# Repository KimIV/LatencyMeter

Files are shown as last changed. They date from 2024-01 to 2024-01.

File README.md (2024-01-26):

# Latency Meter Camera

Устройство для измерения раздержки различных камер и FPV-систем. Оно построено на плате Ардуино Нано и 4х разрядном 7ми-сегментном индиаторе LED 5461AS-1.

**Кнопка:**  Короткое (до 0,5 сек) нажатие переключает показания индикатора между real-time, min, max и sma. Нажатие длительностью от 0,5 до 1,5 сек останавливает и продолжает процесс измерения. Нажатие длительностью более 1,5 сек запускает процесс измерения сначала.

**Внимание!** Программный код поддерживает ТРИ разных взаимных расположения индкатора LED 5461AS и Arduino Nano. Выберите для себя нужную компоновку и задайте правильное значение константы LOCATION_LED5461AS в файле latencymeter.ino. Там же читайте подробности в комментариях перед определением константы LOCATION_LED5461AS.

Видео по сборке для компоновки LOCATION_LED5461AS 0: [https://www.youtube.com/watch?v=69uGeqPZ3CI](https://www.youtube.com/watch?v=69uGeqPZ3CI)



22.01.2024
Добавлены 3Д модели (папка 3D_Model_OutSensors) корпуса устройства для варианта сборки с выносными фоторезистором и светодиодом. Этот вариант удобнее для измерения задержек FPV-систем от курсовой камеры на квадрокоптере до шлема или очков.

24.01.2024
Добавлены 3Д модели держателей выносных элементов, параметры печати, готовые gcode и картинки. Публикация на тему сборки компоновки LOCATION_LED5461AS 1: http://chipgu.ru/viewtopic.php?t=5411

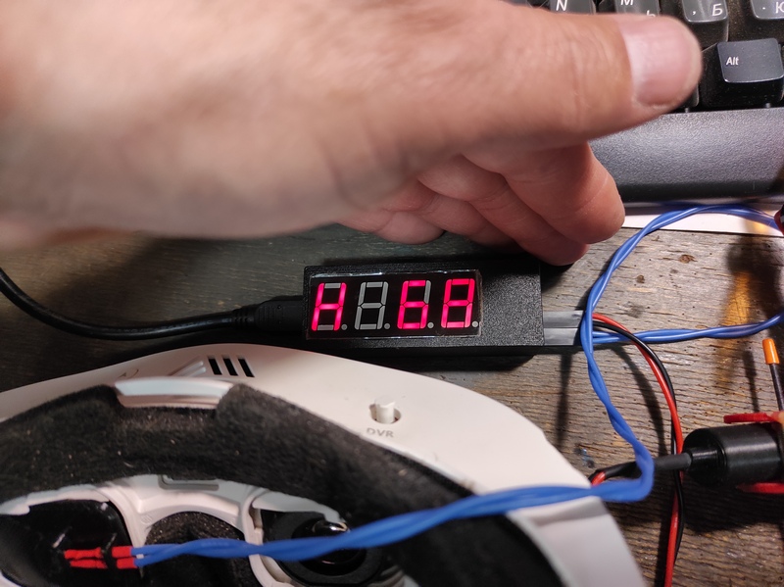
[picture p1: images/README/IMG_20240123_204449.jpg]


26.01.2024
Добавлена новая функция кнопки - возможность остановки/продолжения процесса измерения.

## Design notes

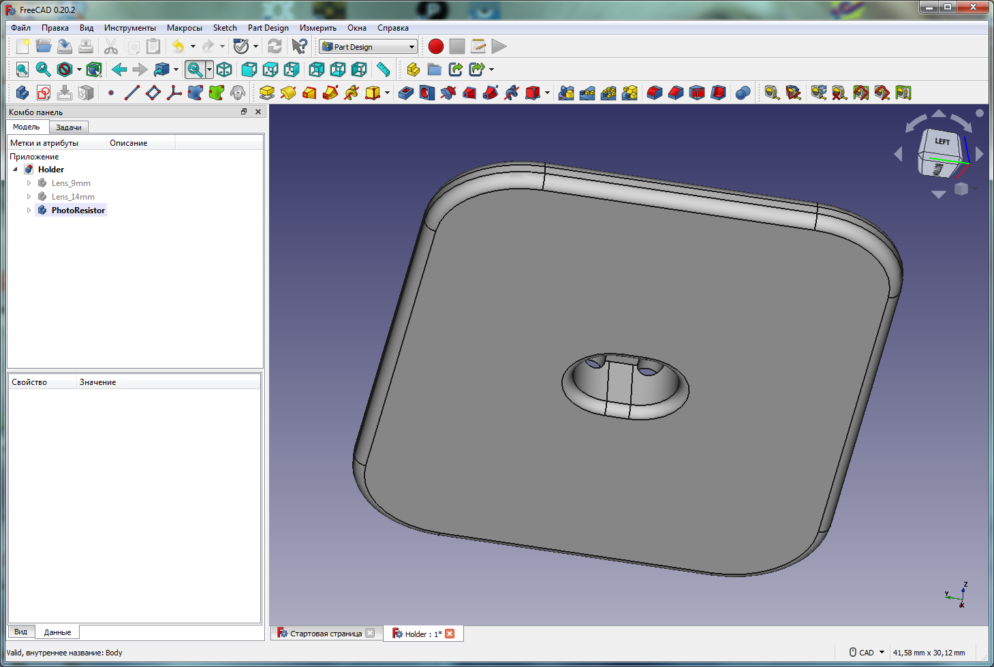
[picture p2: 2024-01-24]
3D_Model_OutSensors/Holder-PhotoResistor_3.png

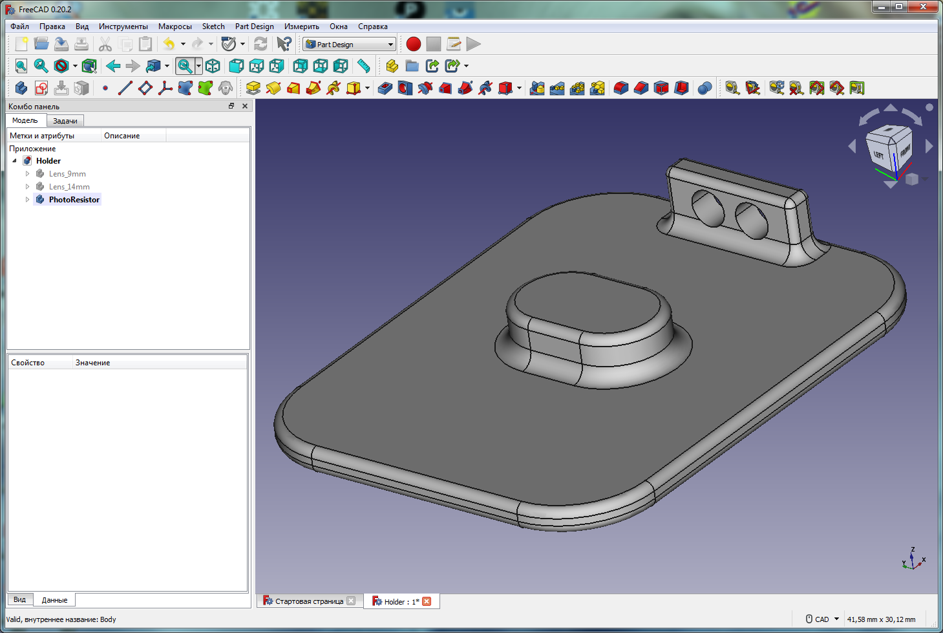
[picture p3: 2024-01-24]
3D_Model_OutSensors/Holder-PhotoResistor_1.png

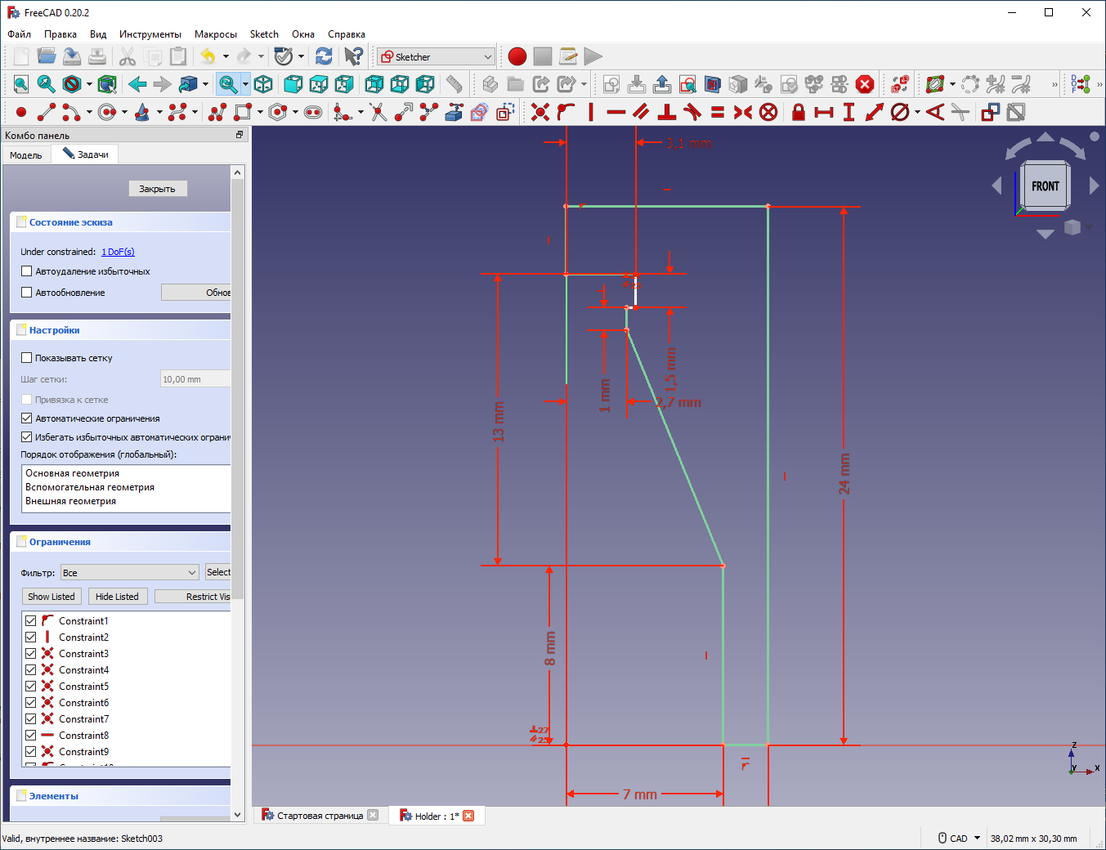
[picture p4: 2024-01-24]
3D_Model_OutSensors/Holder-Lens_14mm_Sketch.png

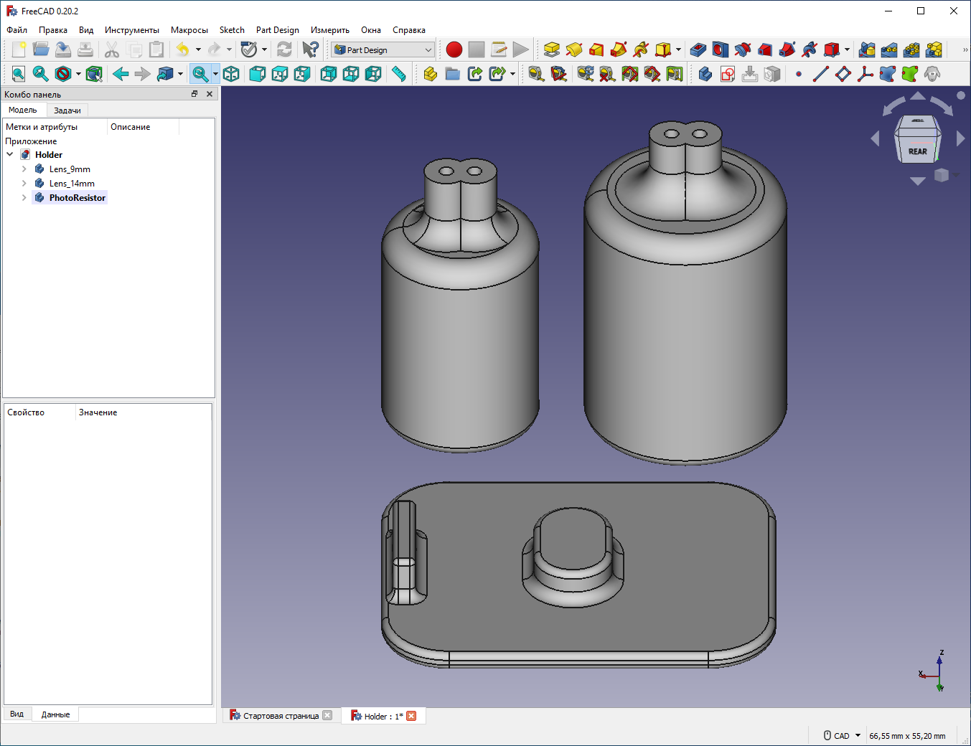
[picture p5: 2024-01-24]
3D_Model_OutSensors/Holders.png

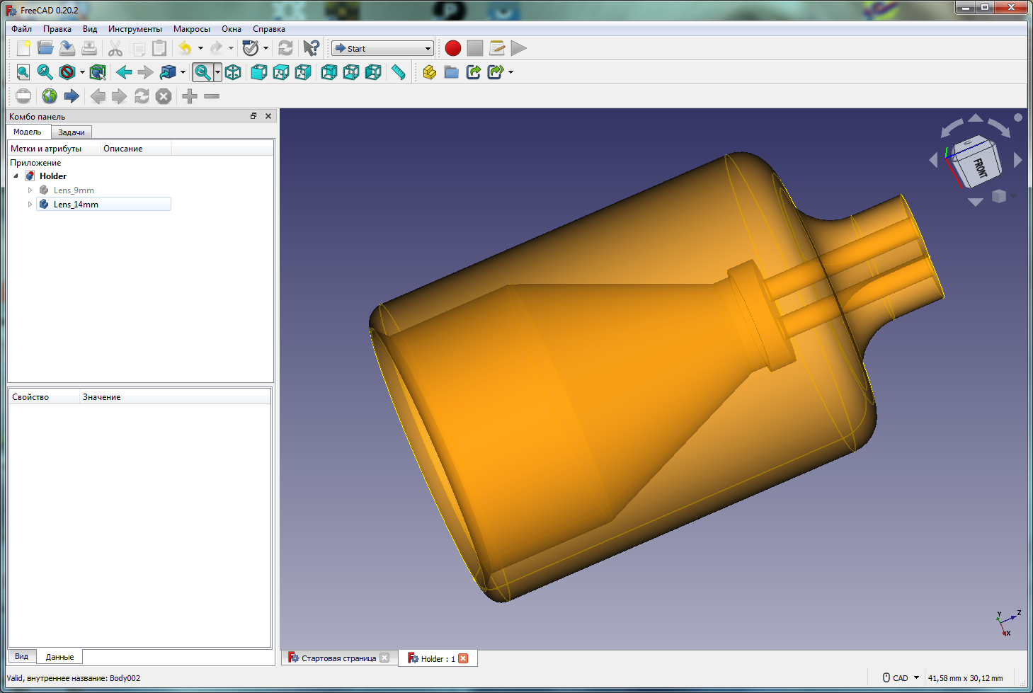
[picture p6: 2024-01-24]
3D_Model_OutSensors/Holder-Lens_14mm.png

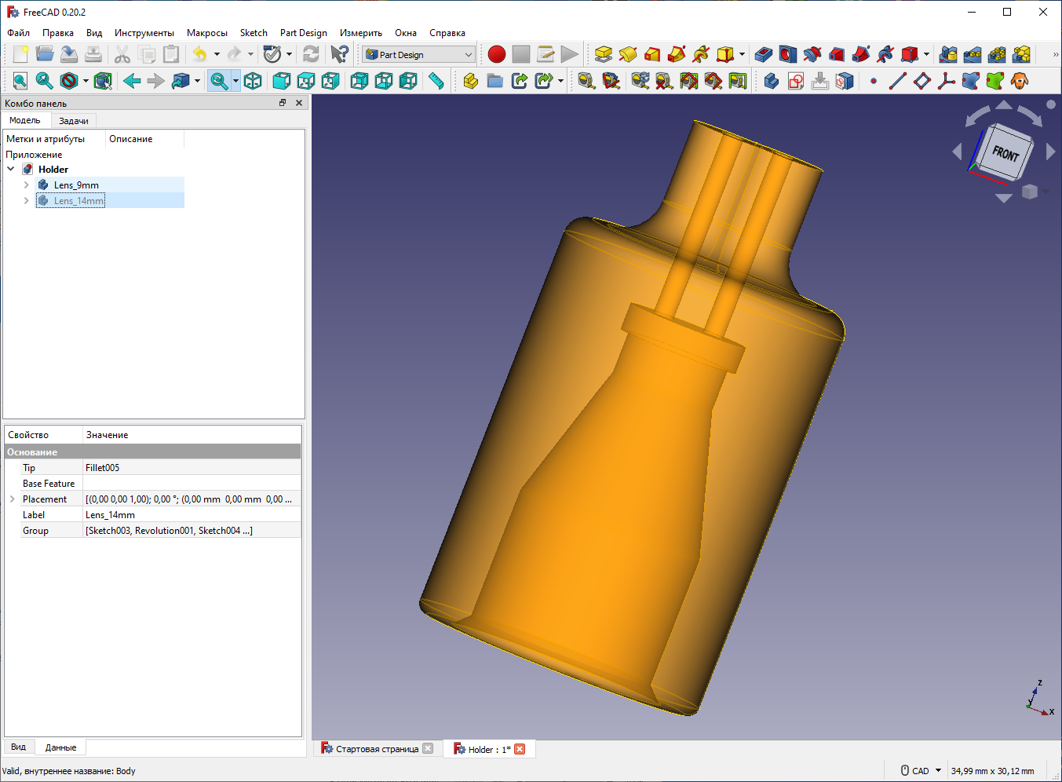
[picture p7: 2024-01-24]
3D_Model_OutSensors/Holder-Lens_9mm.png

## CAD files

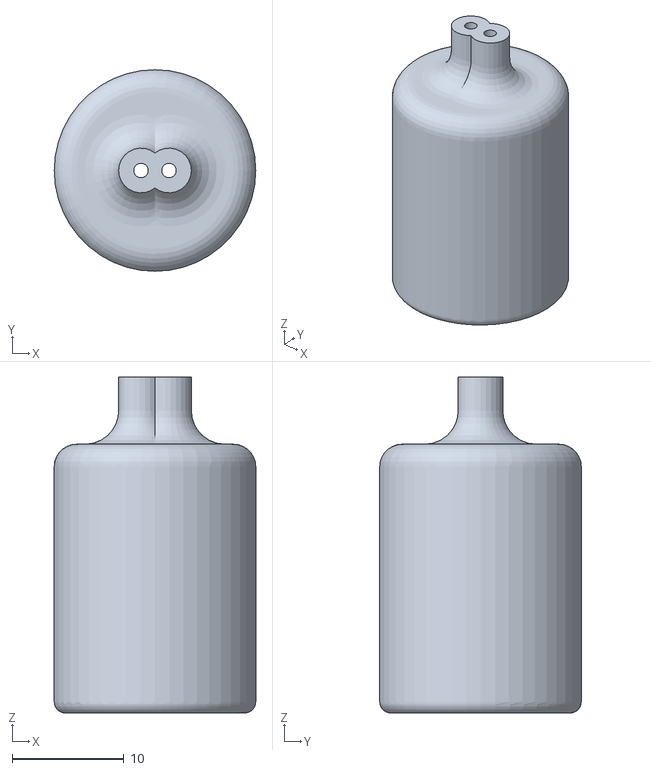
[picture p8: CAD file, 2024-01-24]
3D_Model_OutSensors/Holder-Lens_14mm.stl
18.0 x 18.0 x 30.0

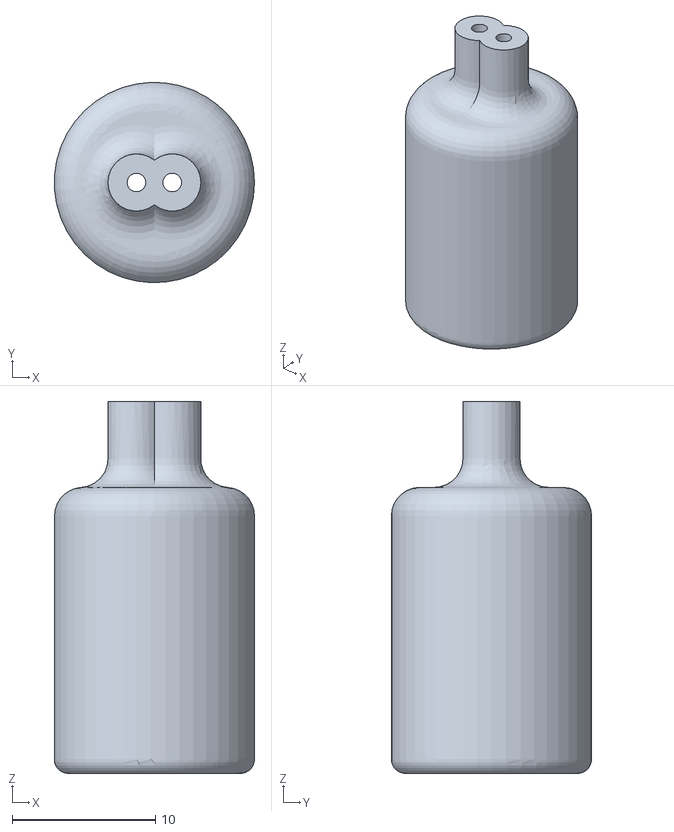
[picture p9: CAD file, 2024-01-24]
3D_Model_OutSensors/Holder-Lens_9mm.stl
14.0 x 14.0 x 26.0

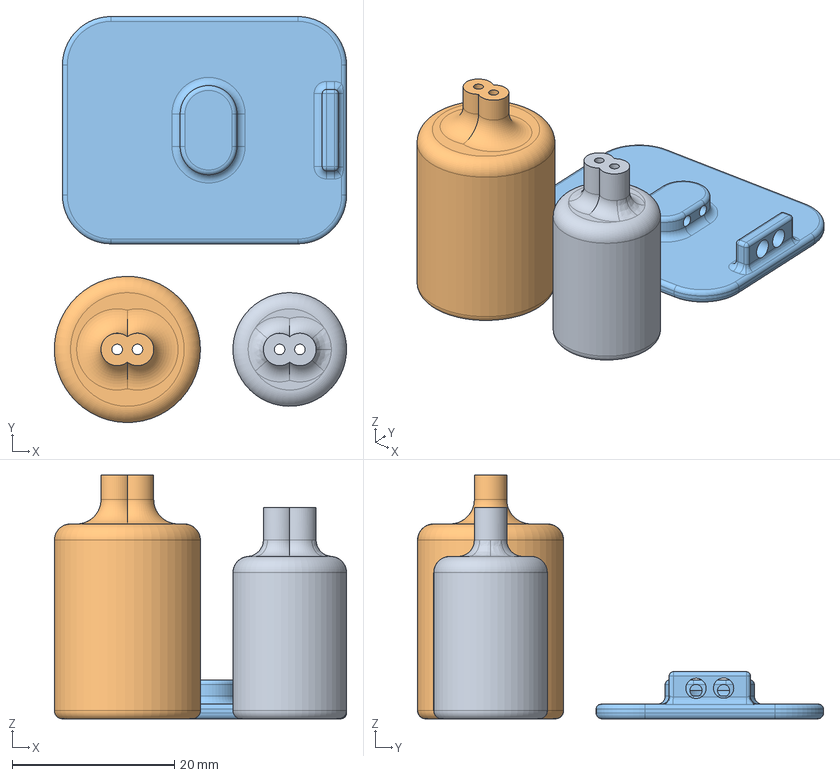
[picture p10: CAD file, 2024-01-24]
3D_Model_OutSensors/Holder.FCStd
36.0 x 50.0 x 30.0 mm
Lens_9mm
Lens_14mm
PhotoResistor

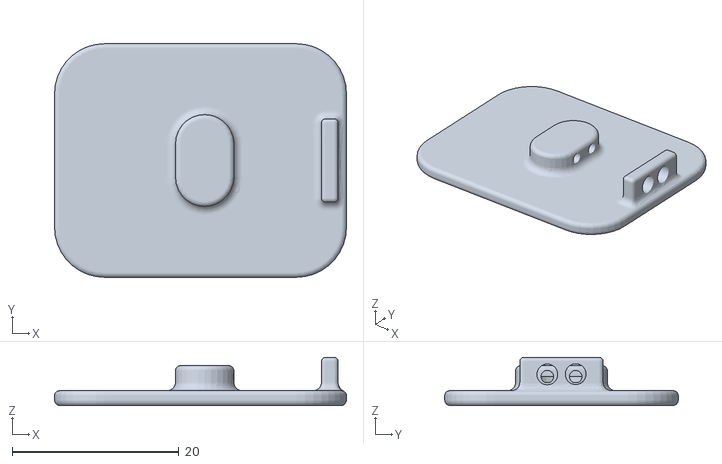
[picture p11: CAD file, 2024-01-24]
3D_Model_OutSensors/Holder-PhotoResistor.stl
35.0 x 28.0 x 5.80

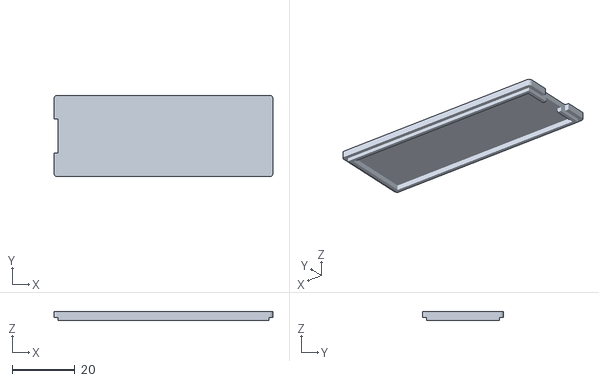
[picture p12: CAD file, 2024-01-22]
3D_Model_OutSensors/LatencyMeter-Cap.stl
70.0 x 26.0 x 3.00

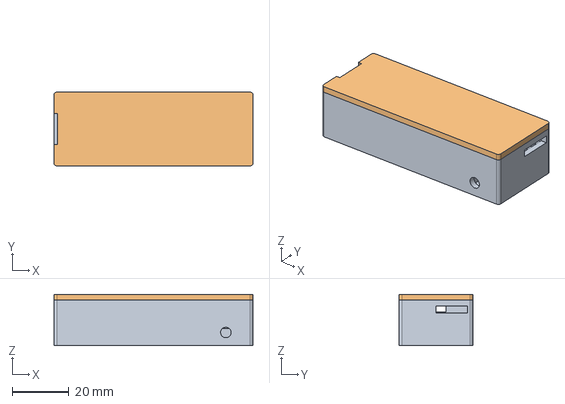
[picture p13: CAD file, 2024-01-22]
3D_Model_OutSensors/LatencyMeter.FCStd
70.0 x 26.0 x 18.0 mm
Cap

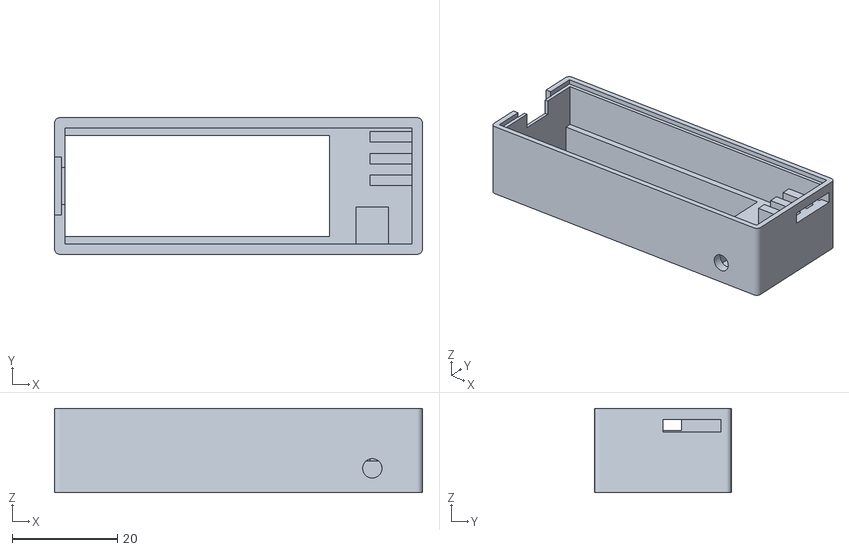
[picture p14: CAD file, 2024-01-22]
3D_Model_OutSensors/LatencyMeter-Body.stl
70.0 x 26.0 x 16.0

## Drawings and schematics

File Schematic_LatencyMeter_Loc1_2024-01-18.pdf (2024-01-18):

A | A

1

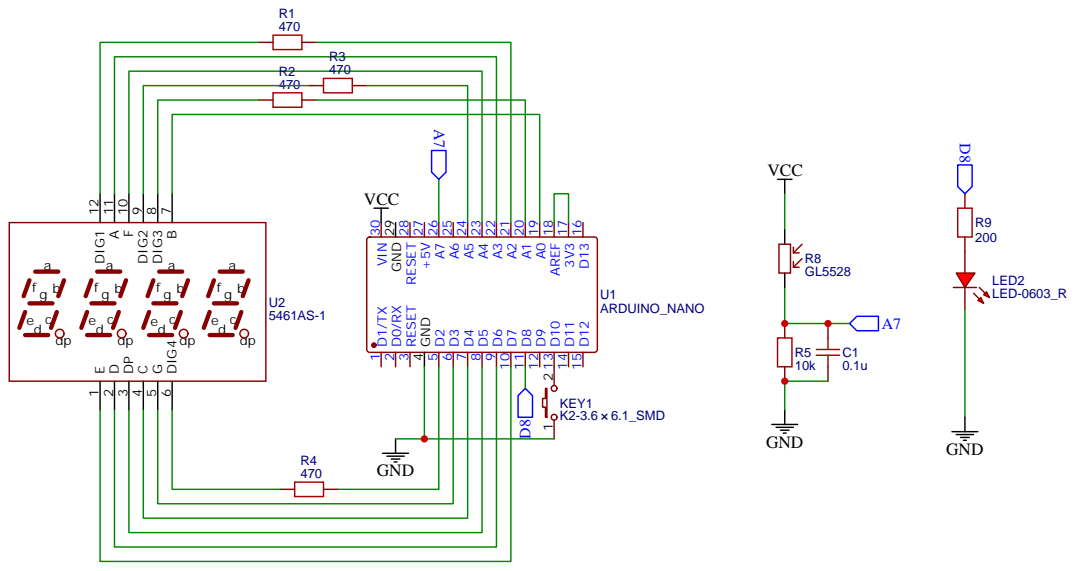
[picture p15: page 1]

D12 15 D13 16 3V3 17 AREF 18 A0 19 A1 20 A2 21 A3 22 A4 23 A5 24 A6 25 A7 26 +5V 27 RESET 28 GND 29 VIN 30

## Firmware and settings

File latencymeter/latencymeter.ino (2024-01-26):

#define F_CPU 16000000UL  // частота работы микроконтроллера
#define PIN_BUTTON 10     // Кнопка

// LOCATION_LED5461AS определяет взаимное расположение Led 5461AS и Arduino Nano
// при двухэтажной компоновке:
//  0 - оригинальная компоновка автора проекта https://github.com/githubniko/LatencyMeter
//      Смотри схему Schematic_Latencycam_2023-11-22.pdf
//  1 - Led 5461AS сдвинут на два контакта в сторону от miniUSB относительно оригинала.
//      Смотри схему Schematic_LatencyMeter_Loc1_2024-01-18.pdf
//  2 - Led 5461AS перевёрнут на 180 градусов относительно оригинала.
//      Смотри схему Schematic_LatencyMeter_Loc2_2024-01-18.pdf
#define LOCATION_LED5461AS 1

#if (LOCATION_LED5461AS == 0)
#include "Led_5461AS.h"
#elif (LOCATION_LED5461AS == 1)
#include "Led_5461AS_2.h"
#else
#include "Led_5461AS_180.h"
#endif

bool _flagClear = false;    // Для мигания в режиме Стоп измерения.
#include "Button.h"
#include "LatencyMeter.h"

Led_5461AS *led;
LatencyMeter *latencyMeter;
Button button1(PIN_BUTTON);

uint8_t flagTypeDataOut = 4;  // 0 - задержка реал-тайм, 1 - минимальная, 2 - максимальная, 3 - медиана, 4 - кол-во измерений

class EventHandler
{
public:
  void OnUpdateData()
  {
    char buf[33];
    char str[10];

    switch (flagTypeDataOut)
    {
    case 1:
      dtostrf(latencyMeter->minTime, 3, 0, buf);
      strcpy(str, "L");
      break;
    case 2:
      dtostrf(latencyMeter->maxTime, 3, 0, buf);
      strcpy(str, "H");
      break;
    case 3:
      dtostrf(latencyMeter->medianTime, 3, 0, buf);
      strcpy(str, "^");
      break;
    case 4:
      itoa(latencyMeter->count, buf, 10);
      strcpy(str, "n");
      break;
    case 0:
    default:
      dtostrf(latencyMeter->valueTime, 4, 0, buf);
      strcpy(str, "");
      break;
    }
    strcat(str, buf);

    // вывод на экран
    if (_flagClear) led->Set("");
    else led->Set(str);
  }

  void OnBtnClick()
  {
    flagTypeDataOut++;
    if (flagTypeDataOut > 4)
      flagTypeDataOut = 0;
    
    OnUpdateData();
  }

  void OnBtnLongClick()
  {
    _flagClear = false;
    latencyMeter->_flagStatus = !latencyMeter->_flagStatus;
  }

  void OnBtnReset()
  {
    _flagClear = false;
    latencyMeter->Start();
  }
};
EventHandler eventHandler;

void setup()
{
  Serial.begin(115200);

  led = new Led_5461AS();
  latencyMeter = new LatencyMeter();
  latencyMeter->onUpdate += METHOD_HANDLER(eventHandler, EventHandler::OnUpdateData);

  button1.onClick += METHOD_HANDLER(eventHandler, EventHandler::OnBtnClick);
  button1.onClickHold += METHOD_HANDLER(eventHandler, EventHandler::OnBtnLongClick);
  button1.onClickLong += METHOD_HANDLER(eventHandler, EventHandler::OnBtnReset);
}

void loop()
{
  button1.Execute();
  latencyMeter->Execute();
}

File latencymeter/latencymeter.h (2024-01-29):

#define PIN_IN 7  // Фоторезистор на A7
#if (LOCATION_LED5461AS == 1)
#define PIN_OUT 8 // Светодиод на D8
#else
#define PIN_OUT 3 // Светодиод на D3
#endif

#include "include/AbstractEventHandler.h"

class LatencyMeter
{
    uint32_t _timer = 0;         // Переменная таймера
    uint32_t _timerClear = 0;    // Переменная таймера для мигания в режиме Стоп
    bool _flagMeasuring = false; // когда true, то идет процесс измерения
    List<uint16_t> _listValue;   // массив измерений

public:
    bool _flagStatus = false;    // Управляет запуском/остановкой процесса измерения
    float startVoltage = 0;
    uint16_t medianTime = 0;  // Медиана значений
    uint16_t minTime = 0;
    uint16_t maxTime = 0;
    uint16_t valueTime = 0;
    uint16_t count = 0;       // Кол-во измерений

    TEvent<> onUpdate;

public:
    LatencyMeter()
    {
        analogReference(EXTERNAL); // внешнее опорное напряжение 3.3В
        pinMode(PIN_OUT, OUTPUT);
    }

    void Start()
    {
        Serial.println("Start");
        medianTime = 0;
        minTime = 0;
        maxTime = 0;
        valueTime = 0;
        count = 0;
        _flagMeasuring = false;
        _listValue.clear();

        onUpdate();
        minTime = 32767;
        digitalWrite(PIN_OUT, LOW); // Выкл. светодиод
        delay(250);
        startVoltage = getVoltage();
        _flagStatus = true;

    }
    void Stop() { _flagStatus = false; }
    void Restart()
    {
        Stop();
        Start();
    }

    /// @brief Выполняет измерение
    void Execute()
    {
        if (!_flagStatus)
        {
          digitalWrite(PIN_OUT, LOW); // Выкл. светодиод при остановке измерений
          if (millis() - _timerClear > 250)
          {
            _flagClear = !_flagClear;
            _timerClear = millis();
            onUpdate();
          }
          return;
        }

        if (!_flagMeasuring)
        {
            // Ждем, пока датчик зафиксирует состояние выкл. светодиода
            if (getVoltage() > startVoltage + 0.2f)
                return;

            _flagMeasuring = true;
            _timer = micros();
            digitalWrite(PIN_OUT, HIGH); // Зажигаем светодиод
        }
        // Ждем, сигнал от фотодатчика
        else
        {
            if (getVoltage() > startVoltage + 0.5f)
            { // Если сигнал поступил, то
                count++;
                valueTime = (micros() - _timer) / 1000; // Считаем задержку
                AddValue(valueTime);

                if (valueTime < minTime)
                    minTime = valueTime;

                if (valueTime > maxTime)
                    maxTime = valueTime;

                medianTime = round(median());

                onUpdate();

                digitalWrite(PIN_OUT, LOW); // Выкл. светодиод
                _flagMeasuring = false;
            }
        }
    }

private:
    /// @brief Получает напряжение на аналоговов входе
    /// @return Возвращяет напряжение
    float getVoltage()
    {
        return (float)(analogRead(PIN_IN) * 3.3) / 1024;
    }

    /// @brief Добавляет измерение в сортированный массив
    /// @return void
    void AddValue(uint32_t value)
    {
        int size = _listValue.getSize();
        if (size > 50)
        { // ограничиваем размeр, чтобы не было переполнения памяти
            _listValue.removeFirst();
        }
        _listValue.add(value);
        Serial.println(value);
    }

    /// @brief Возвращает медиану. Примечание: данные должны быть отсортированы
    /// @return Значение медианы
    float median()
    {
        uint16_t size = _listValue.getSize();

        float median1 = 0;           // хранит значение первой найденой медианы (для четного ряда)
        int limLow = 0, limHigh = 0; // верхний нижний предел
        for (uint16_t i = 0; i < size; i++)
        {
            // Пропускамем, если число вышло за установленные пределы поиска
            if (limLow != 0 && limLow >= _listValue[i])
                continue;
            if (limHigh != 0 && limHigh <= _listValue[i])
                continue;
            // цикл поиска медианы
            int m = 0, // счетчики бОльших и меньших значений
                c = 0; // счетчик повторяющихся значений
            for (uint16_t j = 0; j < size; j++)
            {
                if (i != j) // пропускаем самого себя
                {
                    if (_listValue[i] < _listValue[j])
                        m--;
                    else if (_listValue[i] > _listValue[j])
                        m++;
                    else
                        c++;
                }
            }
            m = c > abs(m) ? 0 : (abs(m) - c) * (m > 0 ? 1 : -1); // это нужно, чтобы определить в какую сторону отнести равные значения ряда

            // для НЕЧЕТНОГО ряда медиана будет одна при m == 0
            if (m == 0)
                return _listValue[i];

            // для ЧЕТНОГО ряда ищем два ближайших кандидата для медианы
            if (abs(m) == 1)
            {
                if (median1 != 0 && (limLow == median1 || limHigh == median1))
                    return (median1 + _listValue[i]) / 2.0f; // вычисляем среднее значение из 2х соседних медиан
                else
                    median1 = _listValue[i]; // первая медиана
            }
            // Выставляем верхний и нижний предел ряда
            if (m < 0)
            {
                if (limLow == 0 || limLow < _listValue[i])
                    limLow = _listValue[i];
            }
            else if(m > 0)
            {
                if (limHigh == 0 || limHigh > _listValue[i])
                    limHigh = _listValue[i];
            }
        }
        return median1;
    }
};

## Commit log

2024-01-18 Новая версия
    Добавлены две компоновки взаимного расположения Led_5461AS и Arduino Nano.
2024-01-18 Update README.md
    Добавлена инфа о константе LOCATION_LED5461AS
2024-01-18 Update latencymeter.ino
    Оригинальная компоновка
2024-01-22 Защита от дребезга
2024-01-22 3D_Model_OutSensors
    3Д модель корпуса LatencyMeter для варианта сборки с выносными фоторезистором и светодиодом.
    [LatencyMeter-Body.stl, LatencyMeter-Cap.stl, LatencyMeter.FCStd]
2024-01-24 Update button.h
    Удалил пустые строки
2024-01-24 Держатели выносных элементов
    Исходники FreeCAD, экспорты STL, параметры печати, готовые gcode и картинки.
    [Holder-Lens_14mm.stl, Holder-PhotoResistor.stl, Holder.FCStd]
2024-01-24 Обновление 3Д моделей
    Немного подправил 3Д модели с учётом результатов печати. Обновил STL и добавил скетчи с размерами.
    [Holder-Lens_14mm.stl, Holder-Lens_9mm.stl, Holder-PhotoResistor.stl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]
2024-01-24 Обновление Readme.md
2024-01-25 Причёсывание кода
    В файле button.h :
    1. Удалено излишнее обнуление таймера _timer = millis();
    2. Добавлены константы таймингов работы кнопки
2024-01-25 Update latencymeter.h
    Поигрался со стартовым напряжением на фоторезисторе и увеличил скорость измерений.
2024-01-26 Обновление
    Исправление ускорения замеров. Часто выскакивали нули и вообще неправильные минимумы.
    Добавил новую функцию кнопки: Stop-Resume измерений.
    [latencymeter.h, latencymeter.ino]
2024-01-26 Update README.md
    Новое описание функционала кнопки.
2024-01-26 Ренейминг
    Переименование событий ближе к сути.
2024-01-26 Мелочи
2024-01-26 Update button.h
    Время короткого удержания кнопки уменьшил до 0,3 сек. Стало удобнее работать. А то часто вместо короткого удержания получался обычный клик.
2024-01-26 Update button.h
    Устранил дребезг при отпускании кнопки
2024-01-26 Мигание в режиме Стоп
2024-01-26 Поправки к миганию
2024-01-29 Update latencymeter.h
    Выключение светодиода при остановке измерения.
